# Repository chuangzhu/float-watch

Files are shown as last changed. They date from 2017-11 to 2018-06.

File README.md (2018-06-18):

# FloatWatch
A smart watch based on [Persistence Of Vision](https://en.wikipedia.org/wiki/Persistence_of_vision).
> * Display __floating__ time in the air
> * Heart rate monitor
> * Pedometer (in progress)

## Images
#### Display
floattime

#### Appearance
floatwatch

#### Heart rate
heartrate

#### Pedometer
pedometer

#### Board
board

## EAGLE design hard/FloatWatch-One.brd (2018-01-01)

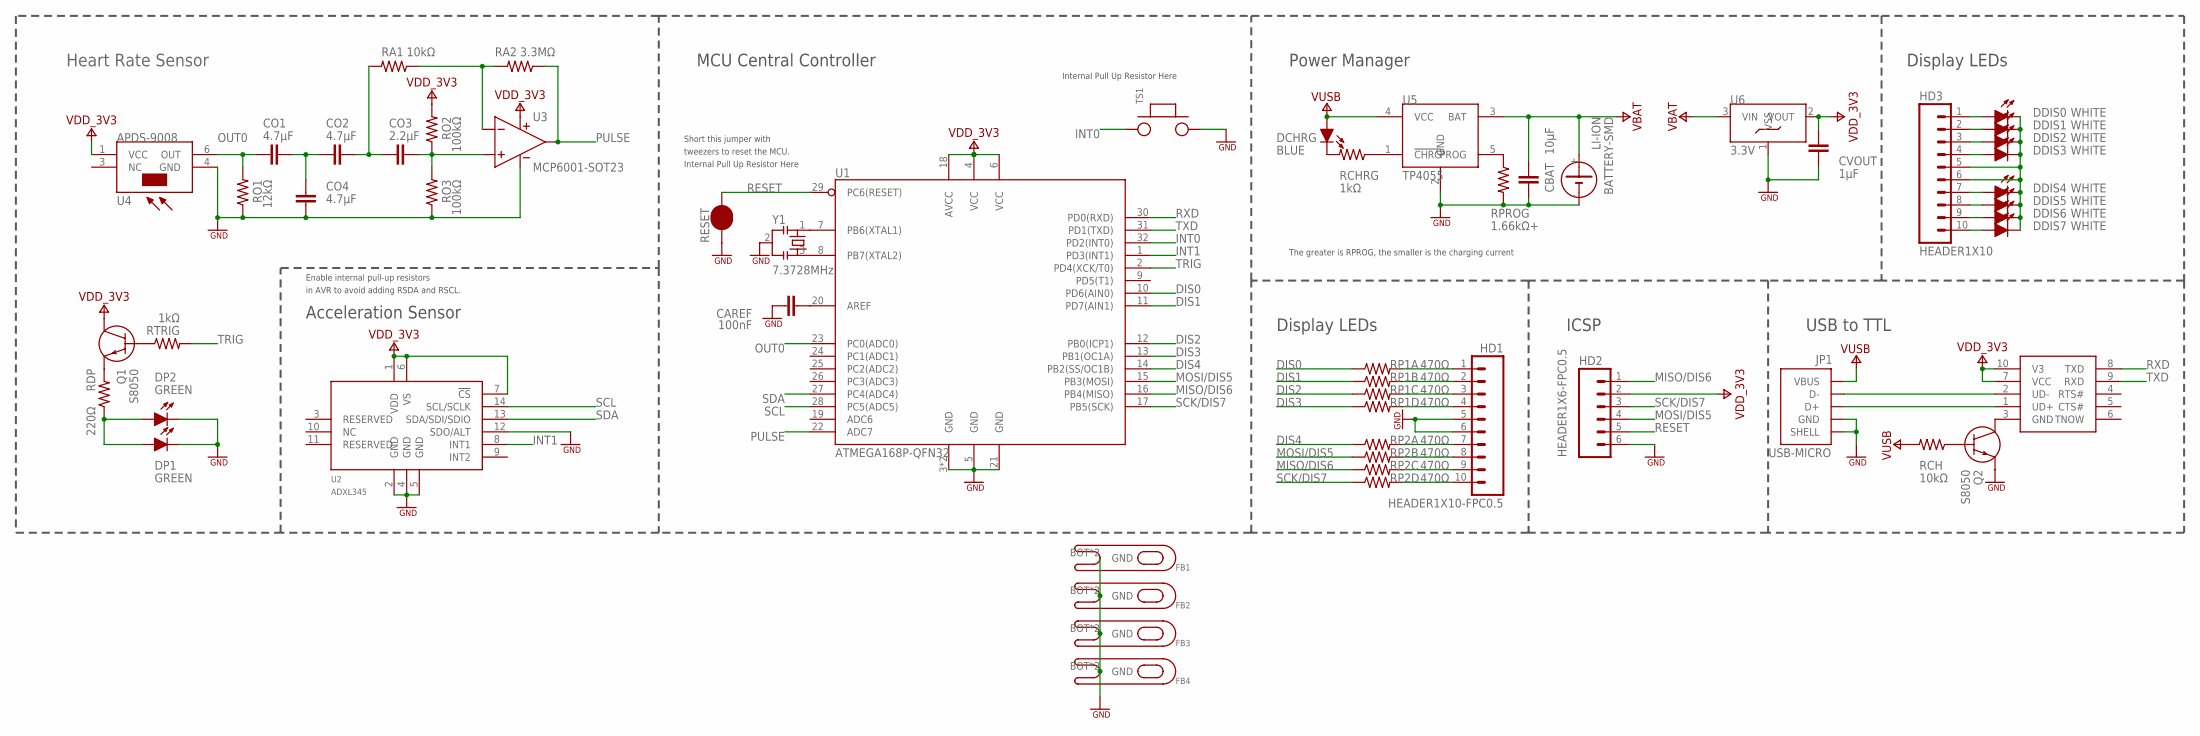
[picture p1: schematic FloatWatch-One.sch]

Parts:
CAREF: 100nF; SMD0603
CBAT: 10μF; SMD0603
CO1, CO2, CO4: 4.7μF; SMD0603
CO3: 2.2μF; SMD0603
CVOUT: 1μF; SMD0603
DCHRG: BLUE; LED-0603
DDIS0, DDIS1, DDIS2, DDIS3, DDIS4, DDIS5, DDIS6, DDIS7: WHITE; LED-0603
DP1, DP2: GREEN; LED-1206
FB1, FB2, FB3, FB4: BROAD-STICK; BOARD-STICK
HD1: HEADER1X10-FPC0.5; FPC0.5-10
HD2: HEADER1X6-FPC0.5; FPC0.5-6
HD3: HEADER1X10; FPC0.5-10-SOLDER
JP1: USB-MICRO
LI-ION: BATTERY-SMD; BAT-SMD
Q1, Q2: S8050; SOT23-0
RA1: 10kΩ; SMD0603
RA2: 3.3MΩ; SMD0603
RCH: 10kΩ; SMD0603
RCHRG: 1kΩ; SMD0603
RDP: 220Ω; SMD0603
RESET: JUMPER-SMD; JMPER-SMD
RO1: 12kΩ; SMD0603
RO2, RO3: 100kΩ; SMD0603
RP1, RP2: 470Ω; RP0603
RPROG: 1.66kΩ+; SMD0603
RTRIG: 1kΩ; SMD0603
TS1: TS-P; TS-3X4P
U1: ATMEGA168P-QFN32; QFN32
U2: ADXL345; LGA14
U3: MCP6001-SOT23; SOT23-5
U4: APDS-9008
U5: TP4055; SOT23-5
U6: 3.3V; SOT23-0
U7: CH340E; MSOP10
Y1: 7.3728MHz; CSTCE

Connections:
!CHRG: RCHRG.1, U5.1 (!CHRG)
!GND: DDIS0.C, DDIS1.C, DDIS2.C, DDIS3.C, DDIS4.C, DDIS5.C, DDIS6.C, DDIS7.C, HD3.5, HD3.6
AREF: CAREF.2, U1.20 (AREF)
DIS0: RP1.1, U1.10 (PD6(AIN0))
DIS1: RP1.3 (1), U1.11 (PD7(AIN1))
DIS2: RP1.5 (1), U1.12 (PB0(ICP1))
DIS3: RP1.7 (1), U1.13 (PB1(OC1A))
DIS4: RP2.1, U1.14 (PB2(SS/OC1B))
DRCHRG: DCHRG.C, RCHRG.2
GND: CAREF.1, CBAT.2, CO4.2, CVOUT.2, DP1.C, DP2.C, FB1.BOT, FB1.TOP, FB2.BOT, FB2.TOP, FB3.BOT, FB3.TOP, FB4.BOT, FB4.TOP, HD1.5, HD1.6, HD2.6, JP1.5 (GND), JP1.P1 (SHELL), JP1.P2 (SHELL), JP1.P3 (SHELL), JP1.P4 (SHELL), LI-ION.-, Q2.2 (E), RESET.1, RO1.1, RO3.1, RPROG.2, TS1.2, U1.3 (GND), U1.5 (GND), U1.21 (GND), U1.EP (GND), U2.2 (GND), U2.4 (GND), U2.5 (GND), U2.12 (SDO/ALT), U3.2 (VSS), U4.4 (GND), U5.2 (GND), U6.1 (VSS), Y1.2
GND(CH340E): Q2.3 (C), U7.3 (GND)
HD0: DDIS0.A, HD3.1
HD1: DDIS1.A, HD3.2
HD2: DDIS2.A, HD3.3
HD3: DDIS3.A, HD3.4
HD4: DDIS4.A, HD3.7
HD5: DDIS5.A, HD3.8
HD6: DDIS6.A, HD3.9
HD7: DDIS7.A, HD3.10
INT0: TS1.1, U1.32 (PD2(INT0))
INT1: U1.1 (PD3(INT1)), U2.8 (INT1)
MISO/DIS6: HD2.1, RP2.5 (1), U1.16 (PB4(MISO))
MOSI/DIS5: HD2.4, RP2.3 (1), U1.15 (PB3(MOSI))
N-IN: RA1.1, RA2.2, U3.4 (IN-)
OUT0: CO1.2, RO1.2, U1.23 (PC0(ADC0)), U4.6 (OUT)
OUT1: CO1.1, CO2.2, CO4.1
OUT2: CO2.1, CO3.2, RA1.2
P-IN: CO3.1, RO2.1, RO3.2, U3.3 (IN+)
PROG: RPROG.1, U5.5 (PROG)
PULSE: RA2.1, U1.22 (ADC7), U3.1 (OUT)
QRP: Q1.2 (E), RDP.2
RDP: DP1.A, DP2.A, RDP.1
RESET: HD2.5, RESET.2, U1.29 (PC6(RESET))
RH0: HD1.1, RP1.2
RH1: HD1.2, RP1.4 (2)
RH2: HD1.3, RP1.6 (2)
RH3: HD1.4, RP1.8 (2)
RH4: HD1.7, RP2.2
RH5: HD1.8, RP2.4 (2)
RH6: HD1.9, RP2.6 (2)
RH7: HD1.10, RP2.8 (2)
RQTRIG: Q1.1 (B), RTRIG.1
RXD: U1.30 (PD0(RXD)), U7.8 (TXD)
SCK/DIS7: HD2.3, RP2.7 (1), U1.17 (PB5(SCK))
SCL: U1.28 (PC5(ADC5)), U2.14 (SCL/SCLK)
SDA: U1.27 (PC4(ADC4)), U2.13 (SDA/SDI/SDIO)
TRIG: RTRIG.2, U1.2 (PD4(XCK/T0))
TRIGND: Q2.1 (B), RCH.1
TXD: U1.31 (PD1(TXD)), U7.9 (RXD)
UD+: JP1.3 (D+), U7.1 (UD+)
UD-: JP1.2 (D-), U7.2 (UD-)
VBAT: CBAT.1, LI-ION.+, U5.3 (BAT), U6.3 (VIN)
VDD_3V3: CVOUT.1, HD2.2, Q1.3 (C), RO2.2, U1.4 (VCC), U1.6 (VCC), U1.18 (AVCC), U2.1 (VDD), U2.6 (VS), U2.7 (!CS), U3.5 (VDD), U4.1 (VCC), U6.2 (VOUT), U7.7 (VCC), U7.10 (V3)
VUSB: DCHRG.A, JP1.1 (VBUS), RCH.2, U5.4 (VCC)
X1: U1.7 (PB6(XTAL1)), Y1.1
X2: U1.8 (PB7(XTAL2)), Y1.3

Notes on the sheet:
MCU Central Controller
Acceleration Sensor
Heart Rate Sensor
Power Manager
ICSP
Display LEDs
Enable internal pull-up resistors
in AVR to avoid adding RSDA and RSCL.
USB to TTL
Internal Pull Up Resistor Here
Short this jumper with
tweezers to reset the MCU.
The greater is RPROG, the smaller is the charging current

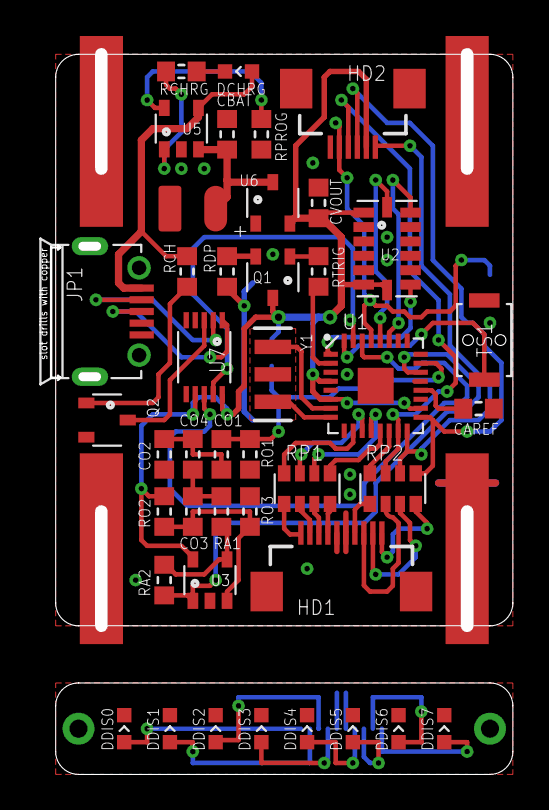
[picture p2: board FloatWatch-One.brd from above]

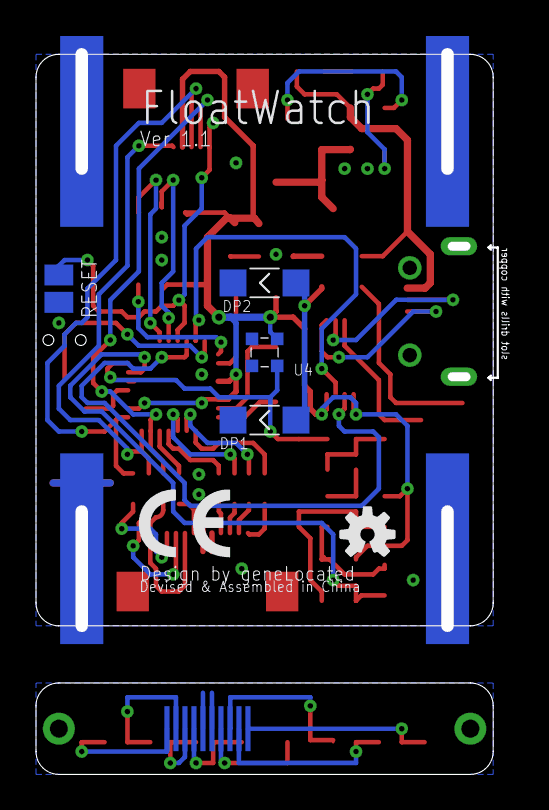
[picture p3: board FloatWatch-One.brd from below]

Board: 2 copper layers, 25.4 x 31.8 mm, 53 parts (7 on the bottom side), 56 nets.

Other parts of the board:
CELOGO: ICON-CE
U$1: ICON-OSHW

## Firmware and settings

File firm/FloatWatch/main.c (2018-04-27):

/*
 * FloatWatch.c
 *
 * Created: 2017/10/4 10:15:04
 * Author : geneLocated
 */ 

#include "main.h"

int main(void)
{
	DDRB=0x3F;	//0011 1111	(XTAL2:0, XTAL1:0, DIS7:1, DIS6:1, DIS5:1, DIS4:1, DIS3:1, DIS2:1)
	DDRD=0xD2;	//1101 0010	(DIS1:1, DIS0:1, PD5:0, TRIG:1, INT1:0, INT0:0, TXD:1, RXD:0)
	set(PORTD, INT0pin);
	//ADC_Init();
	ADXL345_Init();
	//USART_Begin();
	Clock_Init();
	TIMER0_Init();
	//comReg(0xFF);
	//set(PORTD, TRIGpin);
	sei();
    while(1)
    {
		//_delay_ms(10);
    }
}

ISR(TIMER0_OVF_vect)
{
	TCNT0=TCNT0_Init;	//这句必须保留
	{
		ADXL345_GetData();
		if(aZ<-1600)
			disStatus=0;	//允许一个周期开始显示
		if(aZ<350)
			displayTime();
		if(!(PIND & (1<<INT0pin)))
		{
			hour=12;
			minute=0;
			second=0;
		}
	}
}

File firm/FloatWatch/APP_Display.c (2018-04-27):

/*
 * APP_Display.c
 *
 * Created: 2017/10/14 7:21:35
 *  Author: geneLocated
 */ 

#include "APP_Display.h"

unsigned char disStatus=0;	//清零后允许一个周期显示，置位后表示已显示完一个周期

const unsigned char fontData[11][5]=
{	//字体数据，第七位在最上方
	{0x7E, 0xFF, 0x81, 0xFF, 0x7E},	//0
	{0x00, 0x40, 0xFF, 0xFF, 0x00},	//1
	{0x71, 0xF1, 0x87, 0xFD, 0x79},	//2
	{0x63, 0xC3, 0x91, 0xFF, 0x6E},	//3
	{0x38, 0x78, 0xC8, 0xFF, 0xFF},	//4
	{0xE6, 0xE7, 0xA1, 0xBF, 0x9E},	//5
	{0x7E, 0xFF, 0x91, 0x9F, 0x4E},	//6
	{0xE0, 0xC7, 0x9F, 0xF8, 0xE0},	//7
	{0x6E, 0xFF, 0xA1, 0xFF, 0x6E},	//8
	{0x70, 0xF9, 0x8B, 0xFE, 0x7C},	//9
	{0x00, 0x42, 0x66, 0x42, 0x00}	//:
};

void comReg(unsigned char Data)
{
	PORTB|=(Data>>2);
	PORTB&=((Data>>2)+(0xFF<<6));
	PORTD|=(Data<<6);
	PORTD&=((Data<<6)+(0xFF>>2));
}

void displayTime(void)	//显示时间数字下一帧
{
	if(disStatus==0)
	{
		static unsigned char charNum=0;	//时间共有五个字符，之间有四个大的空隙
		static unsigned char colNum=0;	//一个字符有五帧，之间有4个空隙
		unsigned char charInside=11;
		switch(charNum)
		{
			case 0: charInside=hour/10; break;	//时十位
			case 2: charInside=hour%10; break;	//时个位
			case 4: charInside=10; break;	//冒号
			case 6: charInside=minute/10; break;	//分十位
			case 8: charInside=minute%10; break;	//分个位
			default: charInside=11; break;
		}
		if ((charInside!=11) && (colNum%2==0))
			comReg(fontData[charInside][colNum/2]);
		else
			comReg(0x00);
		
		colNum++;
		if(colNum>8)	//算上空隙共8个
		{
			colNum=0;
			charNum++;
		}
		if(charNum>12)
		{
			charNum=0;
			disStatus=1;
		}
	}
}

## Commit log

2017-11-11 This is POVwatch 1.0
    [POVwatch_1.brd, POVwatch_1.sch]
2017-11-11 This is POVwatch 1.0M
    [POVwatch_1.brd, POVwatch_1.sch]
2017-11-11 This is POVwatch 1.0.1 (bugs fixed)
    [POVwatch_1.brd, POVwatch_1.sch]
2017-11-11 This is POVwatch 1.1 (begin)
    [POVwatch_1.brd, POVwatch_1.sch]
2017-11-11 Changed icon position
    [POVwatch_1.brd]
2017-11-11 Changed STICKs size to fit strap
    [POVwatch_1.brd, POVwatch_1.sch]
2017-11-11 Fixed CH340E footprint bug
    [POVwatch_1.brd, POVwatch_1.sch]
2017-11-11 Fix the problem that mask always broken around the crystal
    [POVwatch_1.brd, POVwatch_1.sch]
2017-11-11 Fixed CH340E ground connection
    [POVwatch_1.brd, POVwatch_1.sch]
2017-11-18 Rename to FloatWatch
    [FloatWatch-One.brd, FloatWatch-One.sch]
2017-12-03 Fixes TP4055 footprint bug
    [FloatWatch-One.brd, FloatWatch-One.sch]
2017-12-09 Fixes RPROG resistance
    [FloatWatch-One.brd, FloatWatch-One.sch]
2018-04-27 Ready for repo merge
    [FloatWatch-One.brd, FloatWatch-One.sch]
